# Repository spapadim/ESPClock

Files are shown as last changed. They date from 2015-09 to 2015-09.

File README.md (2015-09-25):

ESP Clock
=========

*Touchscreen clock and light controller with WiFi*

ESPClock video (https://youtu.be/hKBLLkvEEXE)

This was a week-long hack, to build a simple touchscreen clock, with the following features:
* Graphical UI with touch (no buttons)
* Clock synchronization over NTP
* Ability to control WiFi-connected LED lamps
* Web-based configuration UI

This project was partly inspired by the Chumby (remember that?) and by our old X10 light controller (remember *those*!?).  Current iteration's cost is probably comparable to a used Chumby (which also has a lot more features), but it's more fun this way. :)  However, the cost could be taken down to ~$10.

#### Dependencies
* [My rewrite](https://github.com/spapadim/Digole) of the Digole library
* [ArduinoJson](http://github.com/bblanchon/ArduinoJson)
* [Time](http://www.pjrc.com/teensy/td_libs_Time.html)
* Arduino ESP built-in libraries (WiFi, WebServer)

Also, for flashing fonts, you will need the original DigoleSerial library (haven't tested/ported the font upload stuff in my rewrite) and, if you want to substitute your own fonts, the font conversion tools from u8glib/ucglib.

#### BOM
* [Sparkfun Thing](https://www.sparkfun.com/products/13231)
* [Digole 2.4" IPS display](http://digole.com/index.php?productID=1208) (in UART mode, with wire soldered to reset pad)
* 500mAh LiPo (optional, but recommended)
* Depending how fancy you want to get with print finishing: XTC-3D resin and/or Bondo putty, spray paint and primer

More details can be found in the [making-of post](http://bitquill.net/blog/esp8266-light-controller-clock).

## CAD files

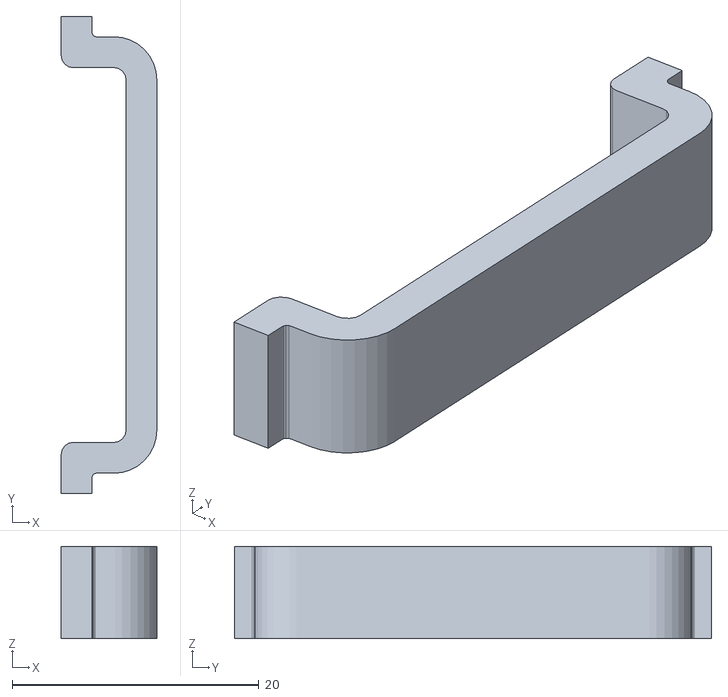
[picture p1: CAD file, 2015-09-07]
cad/bat-clip.stl
7.75 x 38.7 x 7.50

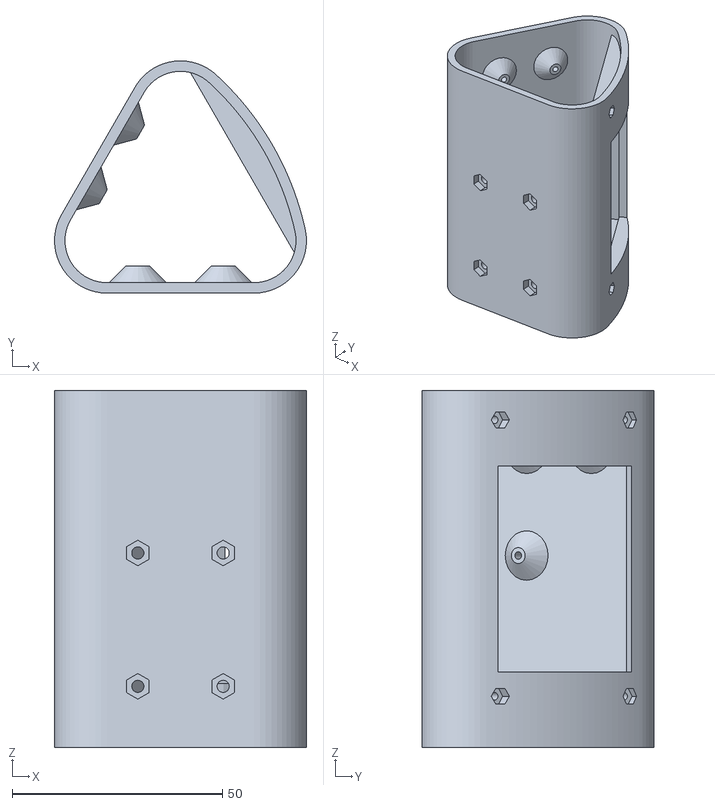
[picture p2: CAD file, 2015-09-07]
cad/case-noribs.stl
60.0 x 55.3 x 85.0

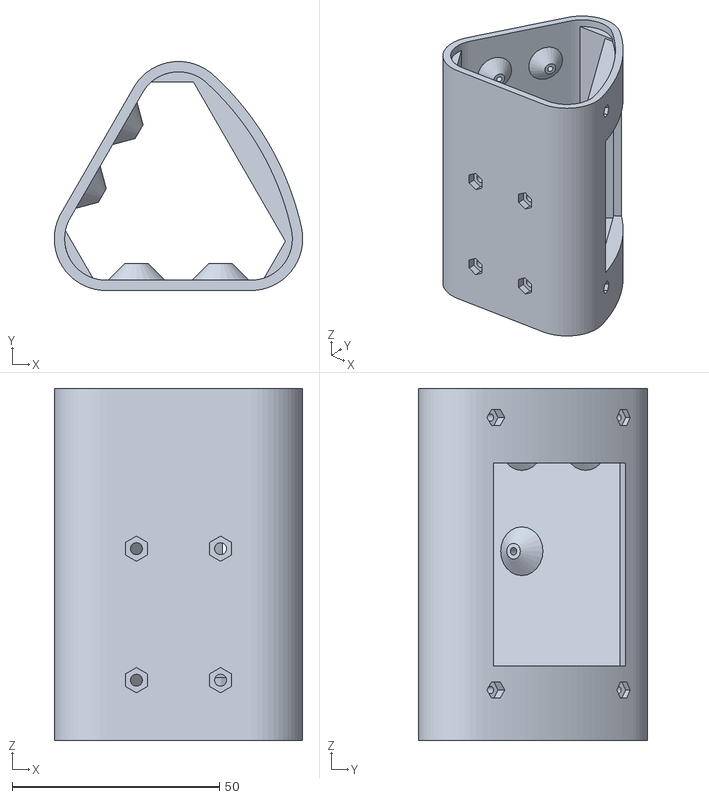
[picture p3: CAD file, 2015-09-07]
cad/case-ribs.stl
60.0 x 55.3 x 85.0

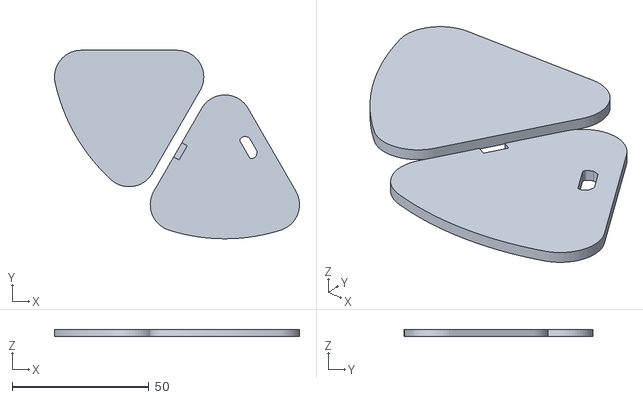
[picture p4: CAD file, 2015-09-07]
cad/caps.stl
89.6 x 69.0 x 2.50

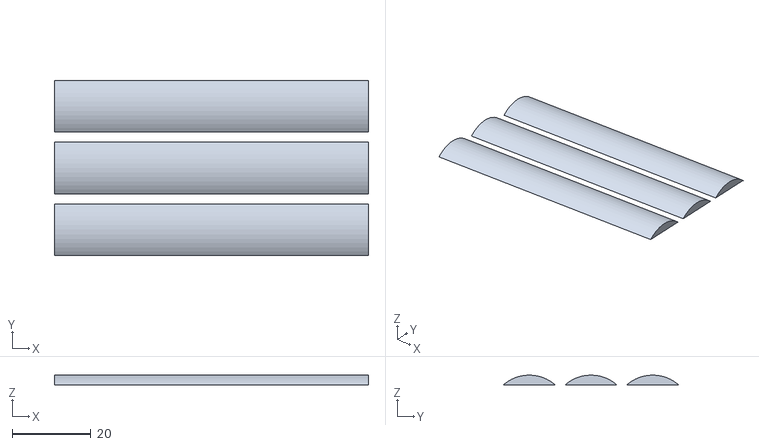
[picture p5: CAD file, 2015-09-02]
cad/ribs.stl
80.0 x 44.7 x 2.50

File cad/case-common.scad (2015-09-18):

inch = 25.4;

thk = 2.5;

r = 10;
side = 55 - 2*r;
//h = 85;
h = (lcd_model == "digole") ? 85 : 90;

curved = true;
curv_ofs = 25;  // larger: less curved

rib_thk = 2.5;  // height of separate glue-on corner ribs

screw_r = 2.9/2;  // M3 tap
nut_r = 6.1/2;  // M3 corner-to-corner
nut_h = 2.25;  // M3 normal
//nut_hjam = 1.8;  // M3 jam nut
screw_rtc_r = 1.8/2;  // M2 tap
nut_rtc_r = 4.35/2; // M2 corner-to-corner
nut_rtc_h = 1.6; // M2 normal
standoff_thk = 1.4; //1.6;
standoff_rtc_thk = 1;
standoff_h = 4;

foot_h = 1;
foot_d = 5;

cap_thk = thk;
cap_slack = 0.2; // PLA/Kossel: -0.1;
cap_notch_w = 6;  // 7;
cap_notch_d = 2.5;  // 2.5;
cap_notch_thk = 2*thk/3;

// SparkFun Thing dimensions

thing_standoff_pos =  [ [0.475, 0.1],  [0.475, 0.9],
                        [1.725, 0.1],  [1.725, 0.9] ] * inch;
thing_xlen = 2.2 * inch;
thing_ylen = 1.0 * inch;
thing_usb_mid_yofs = 0.3 * inch;
thing_usb_edge_xofs = 0;
thing_pcb_thk = 1.55;

// RTC dimensions
rtc_standoff_pos = [ [0.350, 0.075], [1.350, 0.075], [0.350, 0.775] ] * inch; // M2
rtc_xlen = 1.5 * inch;
rtc_ylen = 0.85 * inch;


// LiPo battery dimensions (500mAh, Adafruit or eBay)
bat_w = 29.8 + 0.6;
bat_thk = 5 + 0.25;
bat_l = 35.5;  // not needed
bat_clip_w = 7.5;

usb_micro_thk = 0.5;
usb_slack = 0.35;
module usb_micro_inner_profile() {
  // 0.75 is eyeballed
  polygon([[-5.40/2, 0], [5.40/2, 0], [6.90/2, 0.75],
           [6.90/2, 1.85], [-6.90/2, 1.85], [-6.90/2, 0.75]]);
}

module usb_micro(h, slack = 0) {
  translate([0, usb_micro_thk, 0])
    linear_extrude(height = h) minkowski() {
      usb_micro_inner_profile();
      circle(r = usb_micro_thk + slack, $fn=12);
    }
}


module shell(side, r, h) {
  hull() {
    // Radius and angle of curvature arc
    curv_r = sqrt(side*side + curv_ofs*curv_ofs + sqrt(3)*side*curv_ofs) + r;
    curv_arc_angle = atan(side/(sqrt(3)*side + 2*curv_ofs));
    
    // Curvature circle center (x0, y0)
    x0 = -side/2 - curv_ofs*cos(30);
    y0 = -curv_ofs*sin(30);
    
    // Slice coordinates
    x1 = x0 + curv_r*cos(30-curv_arc_angle);
    y1 = y0 + curv_r*sin(30-curv_arc_angle);
    x2 = x0 + curv_r*cos(30+curv_arc_angle);
    y2 = y0 + curv_r*sin(30+curv_arc_angle);
    
    
    translate([-side/2, 0, 0]) cylinder(r = r, h = h, $fn = 56);
    translate([side/2, 0, 0]) cylinder(r = r, h = h, $fn = 56);
    translate([0, side*cos(30), 0]) cylinder(r = r, h = h, $fn = 56);
    if (curved)
      intersection () {
        translate([x0, y0, 0]) 
          cylinder (r = curv_r, h = h, $fn=36*7);
        linear_extrude(h)
          polygon([[-side/2, 0], [2*x1 + side/2, 2*y1], [2*x2 + side/2, 2*y2]]);
      }
  }
}

//rotate([90, 0, 0]) shell(side, r, h);
//mirror([-1, 0, 0]) shell();

// Virtual jig:
*linear_extrude(120)
  polygon([[-side/2, 0], [side/2, 0], [0, side*cos(30)]]);

// Bring an object to screen position
module scr_position(width) {  // TODO: add rotational displacement?
  curv_r = sqrt(side*side + curv_ofs*curv_ofs + sqrt(3)*side*curv_ofs) + (r + thk);
  chord_dist = sqrt(curv_r*curv_r - width*width/4);
  rofs_adj = chord_dist - curv_ofs - sqrt(3)*side/2 - (r + thk);
  
  zofs = (h - lcd_touch_xlen) / 2 - lcd_touch_xofs;
  rofs = tan(30)*side/2 + r + thk + (curved ? rofs_adj : 0);
  
  angle = 30;  // FIXME: Not properly/consistently used below?
  
  translate([cos(angle)*rofs, sin(angle)*rofs, 0])
    translate([0, tan(30)*side/2, 0])  // move center to epicenter
      rotate([0, 0, angle])  // bring parallel to side
        translate([0, 0, zofs])  // center touch area on face
          children(0);
}

module standoff_cylinder(r1, r2, h, truncated = false) {
  rmax = max(r1,r2);
  rmin = min(r1,r2);
  difference() {
    cylinder(r1 = r1, r2 = r2, h = h);
    if (truncated)  // TODO: Fix nut slightly poking through, if truncated
      translate([-rmax-1, rmin, -1])
        cube([2*rmax+2, rmax+1, h+2]);
  }
}

// TODO(no; will have visible holes on back): Add thing standoffs for mounting USB on other side, as well
face_thk = 1.6; //0.8;
module case(feet = false, rtc = true, ribs = true) {

  
  // Wall
  difference() {
    union() {
      // Main wall
      difference() {
        shell(side, r + thk, h);
        translate([0, 0, -1]) shell(side, r, h+2);
      }
      // Screen mount fill-in
      intersection() {
        shell(side, r + thk, h);
        scr_position(width = lcd_ylen)
           translate([-lcd_scr_h - face_thk, -lcd_ylen/2-lcd_yext/2, -lcd_xext_top])  // move center to origin
            cube([lcd_scr_h + face_thk + 20, lcd_ylen+lcd_yext, lcd_xlen+lcd_xext_top+lcd_xext_bottom]); // TODO: properly adj x for curved
      }
      // Thing standoff positives
      for (pos_xy = thing_standoff_pos)
        translate([pos_xy[1] - thing_ylen/2, -r + standoff_h, thk + pos_xy[0]])
          rotate([90, 0, 0])
            standoff_cylinder(r1 = screw_r + standoff_thk, 
                     r2 = screw_r + standoff_thk + standoff_h, // 45deg slope
                     h = standoff_h, $fn=24);
      // RTC standoff positives
      if (rtc) {
        translate([-cos(30)*(tan(30)*side/2+r), tan(30)*side/2 + sin(30)*(tan(30)*side/2+r), 0]) rotate([0, 0, -120])  // Move to back face; ugly last-minute hack!
        for (pos_xy = rtc_standoff_pos)  
          translate([rtc_ylen/2 - pos_xy[1], standoff_h, h - (2*thk + pos_xy[0])])
            rotate([90, 0, 0])
              standoff_cylinder(r1 = screw_rtc_r + standoff_rtc_thk, 
                       r2 = screw_rtc_r + standoff_rtc_thk + standoff_h, // 45deg slope
                       h = standoff_h, $fn=24);          
      }
      
      // Integrated ribs (optional) to support endcaps
      if (ribs) {
        for (a = [0, 120, 240])
          translate([0, sqrt(3)*side/6, h/2])
            rotate([0, 0, a])
              translate([0, sqrt(3)*side/3 + r - rib_thk, 0])
                rotate([-90, 90, 0])
                  rib();
      }
      
    }
      
    // Screen cutout and standoffs
    scr_position(width = lcd_ylen) union() {
      // Full coutout for touch area
      translate([-lcd_scr_h - face_thk - 1, -lcd_touch_ylen/2, lcd_touch_xofs])
        cube([lcd_scr_h + face_thk + thk + 20, lcd_touch_ylen, lcd_touch_xlen]);  // TODO: properly adj x
      // Partial cutout for screen module
      translate([-lcd_scr_h - face_thk - 1, -lcd_scr_ylen/2, lcd_scr_xofs]) {
        cube([lcd_scr_h + 1, lcd_scr_ylen, lcd_scr_xlen]);
        // Ribbon cable extra cutout
        translate([0, lcd_ribbon_yofs, 0]) 
          cube([lcd_scr_h + 1, lcd_ribbon_ylen, lcd_scr_xlen + lcd_ribbon_xlen]);
        // MCU pin header extra cutout
        translate([0, lcd_header_yofs, lcd_header_scr_xofs-lcd_header_xlen]) 
          cube([lcd_header_h + 1, lcd_header_ylen, lcd_header_xlen]);
        if (lcd_model == "digole") {
          // PenIRQ pin extra cutout; TODO: name constants 3 and 3.5 below
          translate([0, lcd_ribbon_yofs, 0]) 
            cube([lcd_header_h + 1, 3, lcd_scr_xlen + lcd_ribbon_xlen + 3.5]);
        }
      }
    }
    // Screen mounting holes
    scr_position(width = lcd_ylen)
      for (pos_xy = lcd_standoff_pos)
        translate([-lcd_scr_h-face_thk-1, -lcd_ylen/2 + pos_xy[1], pos_xy[0]])
          rotate([0, 90, 0]) {
            cylinder(r = screw_scr_r, h = lcd_scr_h + face_thk + 1, $fn=24);
            translate([0, 0, lcd_scr_h + face_thk + 1 - 0.05 - nut_scr_h])
              rotate([0, 0, 30])  
                cylinder(r = nut_scr_r, h = 10, $fn=6);
          }
    // Thing standoff negatives
    for (pos_xy = thing_standoff_pos)

      translate([pos_xy[1] - thing_ylen/2, -r + standoff_h, cap_thk + pos_xy[0]])
        rotate([90, 0, 0]) {
          translate([0, 0, -1]) cylinder(r = screw_r, h = standoff_h+thk+2, $fn=24);
          translate([0, 0, standoff_h+thk-(nut_h + 0.2)]) rotate([0, 0, 30]) cylinder(r = nut_r, h = (nut_h+0.2)+1, $fn=6);  // TODO: name 0.2 (see also below)

        }
    // RTC standoff negatives
    if (rtc) {
        translate([-cos(30)*(tan(30)*side/2+r), tan(30)*side/2 + sin(30)*(tan(30)*side/2+r), 0]) rotate([0, 0, -120])  // Move to back face; ugly last-minute hack!
      for (pos_xy = rtc_standoff_pos)  
        translate([rtc_ylen/2 - pos_xy[1], standoff_h, h - (2*thk + pos_xy[0])])
          rotate([90, 0, 0]){
            translate([0, 0, -1]) cylinder(r = screw_rtc_r, h = standoff_h+thk+2, $fn=24);
            translate([0, 0, standoff_h+thk-(nut_rtc_h+0.6)]) rotate([0, 0, 30]) cylinder(r = nut_rtc_r, h = (nut_rtc_h+0.6)+1, $fn=6);  // TODO: name 0.6 constant (extra sink to allow covering nuts with putty)
          }
      }
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

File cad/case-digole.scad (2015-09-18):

part = "case";  // [case,caseribs|ribcase,endcaps|caps,ribs,clip]

include <lcd-digole.scad>
include <case-common.scad>

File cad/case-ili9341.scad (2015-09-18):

part = "case";  // [case,caseribs|ribcase,endcaps|caps,ribs,clip]

include <lcd-ili9341.scad>
include <case-common.scad>

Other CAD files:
cad/clock-case.scad
cad/lcd-digole.scad
cad/lcd-ili9341.scad

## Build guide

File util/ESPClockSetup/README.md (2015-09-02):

Auxilliary script to load user fonts into Digole module.

Needs Digole's `DigoleSerial` library (untested otherwise).

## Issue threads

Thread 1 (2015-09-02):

Improve initial setup

spapadim, 2015-09-02:
Sort out the AP->AP+STA->STA transitions and make initial setup work more smoothly.

Currently, it's either AP or STA, until reboot.  Disconnecting from the soft-AP got the station i/f to hang?

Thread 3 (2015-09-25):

Fix minified HTML

spapadim, 2015-09-25:
Minifier (css-html-js-minify.py) does not really support HTML with embedded JS; current minified settings.html is broken.

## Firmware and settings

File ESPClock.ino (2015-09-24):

#include <Arduino.h>
#include <Wire.h>
#include <SPI.h>
#include <EEPROM.h>
#include <Time.h>
#include <ESP8266WiFi.h>
#include <WiFiClient.h>
#include <ESP8266mDNS.h>
#include <ESP8266WebServer.h>
#include <ArduinoJson.h>
#include <Digole.h>

#include "Settings.h"
#include "Config.h"

#include "Font.h"
#include "Widget.h"
#include "Screen.h"

#include "NTPClient.h"
#include "WiFiLamp.h"
#include "WebServer.h"
#include "OWMClient.h"


static const char DEFAULT_AP_PASSWORD[] = "esp";
static const char WIFI_CONNECT_TIMEOUT = 10;  // in seconds

static const time_t NTP_SYNC_INTERVAL = 3600;  // in seconds
static const time_t OWM_UPDATE_INTERVAL = 1800;  // in seconds

extern Label lbl_time, lbl_date, lbl_splash_top, lbl_splash_bottom;
extern Button btn_on, btn_preset, btn_off;
extern Button btn_dev0, btn_dev1, btn_dev2;
extern Button *buttons[];

static Button *active_button = 0;  // Last active button

static Button *find_button(Button **buttons, uint16_t x, uint16_t y) {
  Button **b;
  for (b = buttons; (*b) != 0; b++) {
    if ((*b)->contains(x, y))
      break;
  }
  return *b;
}

static inline void update_backlight(bool on, time_t time_now = 0) {
  static time_t last_on = 0;

  if (time_now == 0)
    time_now = now();

  if (on) {
#if !defined(DIGOLE_SERIAL) || !DIGOLE_SERIAL
    //Serial.println("BL WAKE");  // DEBUG
#endif
    last_on = time_now;
    LCD.setBacklight(BACKLIGHT_ON);
  } else if (last_on > 0 && time_now > last_on + BACKLIGHT_TIMEOUT) {
#if !defined(DIGOLE_SERIAL) || !DIGOLE_SERIAL
    //Serial.println("BL SLEEP");  // DEBUG
#endif
    last_on = 0;
    LCD.setBacklight(BACKLIGHT_OFF);
    LCD.setBacklight(BACKLIGHT_OFF);  // Digole bug: needs second command; not sure with turning on is ok with one
  }
}

static uint8_t selected_dev = 0;
static uint8_t cur_preset = 0;

static void touch_down_or_move_cb(uint16_t x, uint16_t y) {
  update_backlight(true);

  Button *b = find_button(buttons, x, y);
  if (b != active_button) {
    if (active_button != 0) {
      active_button->setActive(false);
      active_button->draw();
      active_button = 0;
    }
    if (b != 0) {
      b->setActive(true);
      b->draw();
      active_button = b;
    }
  }
}

static void touch_up_cb(uint16_t x, uint16_t y) {
  Button *b = find_button(buttons, x, y);

#if !defined(DIGOLE_SERIAL) || !DIGOLE_SERIAL
  if (b != 0) {
    Serial.print("Button press: "); Serial.println(b->getLabel()); Serial.flush();   // DEBUG
  }
#endif

  if (active_button != 0) {
    active_button->setActive(false);
    active_button->draw();
    active_button = 0;
  }

  if (b != 0) {
    uint8_t b_id = b->getId();
    if (b_id >= ID_DEV0) {
      // Update selected button
      uint8_t i_dev = b_id - ID_DEV0;
      buttons[3 + selected_dev]->setPressed(false);
      buttons[3 + selected_dev]->draw();
      buttons[3 + i_dev]->setPressed(true);
      buttons[3 + i_dev]->draw();
      selected_dev = i_dev;
    } else if (b_id == ID_OFF) {
      bool res = WiFiLamp.lampOff(selected_dev);
      //lcdDebugPrintf(0, "OFF(%d) = %d", (int)selected_dev, (res ? 1 : 0));
    } else if (b_id == ID_ON) {
      bool res = WiFiLamp.lampOn(selected_dev);
      //lcdDebugPrintf(0, "ON(%d) = %d", (int)selected_dev, (res ? 1 : 0));
    } else if (b_id == ID_PRESET) {
      WiFiLamp.lampPreset(selected_dev, cur_preset);
      cur_preset = (cur_preset + 1) % SettingsClass::N_PRESETS;
    }
  }
}

static void update_time(bool force = false) {
  static time_t last_update = 0;
  static char buf[12];
  static char led_state = LOW;

  time_t time_now = now();

  update_backlight(false, time_now);

  if ((time_now != last_update && (time_now % 60) == 0) || force) {
    int hr = hour();
    sprintf(buf, "%02d:%02d", hr, minute());
    lbl_time.setLabel(buf);
    lbl_time.draw();
#if !defined(DIGOLE_SERIAL) || !DIGOLE_SERIAL
    Serial.print("New time: "); Serial.println(buf);  Serial.flush();  // DEBUG
#endif

    if (hr == 0 || force) {
      // Need to break up into two sprintf() because Time library uses static buffer
      sprintf(buf, "%3s", dayShortStr(weekday()));
      sprintf(buf + 3, ", %3s %2d", monthShortStr(month()), day());
      lbl_date.setLabel(buf);
      lbl_date.draw();
    }

    last_update = time_now;
  }
}

static void connect_wifi() {
  if (Settings.ssid[0] != '\0') {
    WiFi.hostname(Settings.hostname);
    WiFi.begin(Settings.ssid, Settings.password);
    int s = 0;
    while ((WiFi.status() != WL_CONNECTED) && (s < 2*WIFI_CONNECT_TIMEOUT)) {
      delay(500);  // Must match while condition above
      ++s;
    }
  }

  if (WiFi.status() != WL_CONNECTED) {
    // Fall back to soft-AP mode
    WiFi.softAP(Settings.hostname, DEFAULT_AP_PASSWORD);
  }
}

static void time_cb(time_t time) {
  setTime(time);
  update_time(true);
}

static void weather_cb(const OWMClient::WeatherInfo &conditions) {
  // TODO
}


void setup() {
  char buf[40];
  
#if !defined(DIGOLE_SERIAL) || !DIGOLE_SERIAL
  Serial.begin(115200);
  Serial.println("**** START ****");
#endif
  
  Settings.begin();

  LCD.begin();
  Touch.begin(touch_down_or_move_cb, touch_down_or_move_cb, touch_up_cb);

  LCD.setDisplayConfig(false);
  LCD.clearScreen();
  LCD.setRotation(Digole::ROT270);

  lbl_splash_top.setAlignment(Label::BOTTOM);
  lbl_splash_bottom.setAlignment(Label::TOP);
  lbl_time.setFont(201, &metric_DroidMono50);
  lbl_time.setJustification(Label::LEFT);
  lbl_time.setMargin(0);
  lbl_date.setFgColor(GRAY);
  lbl_date.setJustification(Label::LEFT);
  lbl_date.setMargin(12);
#if defined(_DIGOLE_KLUDGE) && _DIGOLE_KLUDGE
  lbl_time.setDrawMode(Digole::MODE_COPY);
  lbl_date.setDrawMode(Digole::MODE_COPY);
  lbl_splash_top.setDrawMode(Digole::MODE_COPY);
  lbl_splash_bottom.setDrawMode(Digole::MODE_COPY);
#endif

  lbl_splash_top.draw();
  if (Settings.hostname[0] != '\0') {
    lbl_splash_bottom.setLabel(Settings.hostname);
    lbl_splash_bottom.draw();
    delay(1000);
  }
  // otherwise, lbl_splash_bottom is just "" initially
  
  update_backlight(true);

  btn_dev0.setPressed(true);
  selected_dev = 0;

  delay(200);

  snprintf(buf, sizeof(buf), "%s..", Settings.ssid);
  lbl_splash_top.setLabel("Connecting to");
  lbl_splash_bottom.setLabel(buf);
  lbl_splash_top.draw();
  lbl_splash_bottom.draw();
  connect_wifi();

  if (WiFi.status() == WL_CONNECTED) {
    NTPClient.begin(time_cb);
    OWM.begin(weather_cb);
    WiFiLamp.begin();

    // Clear splashscreen and show main UI
    LCD.clearScreen();
    LCD.setRotation(Digole::ROT270);  // clearScreen resets orientation??
    lbl_time.draw();
    lbl_date.draw();

    // Draw all buttons
    for (Button **b = buttons; (*b) != 0; b++)
      (*b)->draw();

    NTPClient.startRequest();
    OWM.startUpdate();
  } else {
    // Display brief configuration instructions
    lbl_splash_top.setLabel("Please connect to ESP_xxx");
    lbl_splash_bottom.setLabel("wifi to configure.");
    lbl_splash_top.draw();
    lbl_splash_bottom.draw();
  }
  WebServer.begin();
}

void loop() {
  WebServer.loop();
  Touch.loop();
  update_time();

  if (WiFi.status() == WL_CONNECTED) {
    NTPClient.loop();
    OWM.loop();

    static time_t last_ntp = 0, last_owm = 0;
    time_t t_now = now();
    if (t_now - last_ntp > NTP_SYNC_INTERVAL) {
      NTPClient.startRequest();
      last_ntp = t_now;
    }
    if (t_now - last_ntp > OWM_UPDATE_INTERVAL) {
      OWM.startUpdate();
      last_owm = t_now;
    }
  }
}

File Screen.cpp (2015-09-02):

#include <Arduino.h>
#include <Wire.h>
#include <Digole.h>

#include "Config.h"
#include "Screen.h"
#include "Widget.h"  // for WHITE

#if defined(DIGOLE_I2C) && DIGOLE_I2C
Digole::DigoleI2C LCD(Wire, 0x27);
#elif defined(DIGOLE_SERIAL) && DIGOLE_SERIAL
Digole::DigoleSerial LCD(Serial, 115200, DISPLAY_RESET_PIN);
#elif defined(DIGOLE_SPI) && DIGOLE_SPI
#  if defined(ESP8266)
Digole::DigoleSoftSPI LCD(4, 13, 12, 14);
//Digole::DigoleSPI LCD(4, 13);
#  else
//Digole::DigoleSoftSPI LCD(10, 12, 11, 13);
Digole::DigoleSPI LCD(10, 12);
#  endif
#endif

Touchscreen Touch;

// We can't use Serial in UART mode, might as well use screen itself
void lcdDebugPrintf(int16_t y, const char *fmt, ...) {
  va_list arg;
  int res;
  char buf[100];

  va_start(arg, fmt);
  vsnprintf(buf, sizeof(buf), fmt, arg);
  va_end(arg);
  
  LCD.setFont(200);
  LCD.setTextPosition(0, y);
  LCD.setDrawMode(Digole::MODE_COPY);
  LCD.setColor(WHITE);
  LCD.print(buf);
}

Touchscreen::Touchscreen()
: _down_cb(0), _move_cb(0), _up_cb(0), 
  _last_x(0xffff), _last_y(0xffff), 
  _state(STATE_IDLE), _last_release_time(0) {
  
}

void Touchscreen::begin(touch_cb_t down_cb, touch_cb_t move_cb, touch_cb_t up_cb) {
  _down_cb = down_cb;
  _move_cb = move_cb;
  _up_cb = up_cb;

  attachInterrupt(INT_PIN, _touchInterrupt, FALLING);
}

void Touchscreen::loop() {
  if (_state == STATE_IDLE)
    return;

  uint16_t t_now = millis();
  uint16_t x, y;
  LCD.readTouchscreen(x, y, Digole::TOUCH_DOWN_NONBLOCKING);

#if !defined(DIGOLE_SERIAL) || !DIGOLE_SERIAL
  Serial.println(); Serial.print("POS "); Serial.print(x); Serial.print(','); Serial.println(y);  // DEBUG
#endif

  // CAUTION: Docs claim no-touch returns 0xffff, 0xffff,
  //   but that does not seem to be the case
  
  switch (_state) {
  case STATE_RELEASED:
    if (x > 0xff00 || y > 0xff00) {
      if (t_now - _last_release_time > DEBOUNCE_MS) {
        if (_up_cb)
          _up_cb(_last_x, _last_y);
        _state = STATE_IDLE;
        _last_x = _last_y = 0xffff;
      }
      break; 
    } else {
      _state = STATE_TOUCHING;
      // Do not break; fall through next case
    }
  case STATE_TOUCHING:
    if (x> 0xff00 || y > 0xff00) {
      _state = STATE_RELEASED;
      _last_release_time = t_now;
    } else {
      if (_last_x == 0xffff && _last_y == 0xffff) {
        if (_down_cb)
          _down_cb(x, y);
      } else if (_last_x != x || _last_y != y) {
        if (_move_cb && 
            (abs((int16_t)x - (int16_t)_last_x) > MOVE_THRESHOLD && 
             abs((int16_t)y - (int16_t)_last_y) > MOVE_THRESHOLD))
          _move_cb(x,y);
      }
      _last_x = x;
      _last_y = y;
    }
    break;
  }
}

void Touchscreen::_touchInterrupt() {
  //Serial.print('T');  // DEBUG
  if (Touch._state != STATE_IDLE)
    return;
  Touch._state = STATE_TOUCHING;
}

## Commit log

2015-09-02 Initial import (working version).
    [bat-clip.stl, caps.stl, case-noribs.stl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]
2015-09-07 Tweak case dimensions (after ABS test-prints)
    [bat-clip.stl, caps.stl, case-noribs.stl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]
2015-09-18 Refactor SCAD code (still has loose ends), and add case version for ILI9341 module (not yet test-fitted).
    [case-common.scad, case-digole.scad, case-ili9341.scad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]
2015-09-24 Feature: Add OpenWeatherMaps client (protocol tested; UI still missing/untested) Feature: Add some API endpoints for controlling lamps via web (HTML UI missing) Bugfix: URL-decode form field values (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
    [ESPClock.ino]
2015-09-25 Add support for OTA firmware update (won't work on boards with 512KB flash, e.g., Sparkfun Thing).
